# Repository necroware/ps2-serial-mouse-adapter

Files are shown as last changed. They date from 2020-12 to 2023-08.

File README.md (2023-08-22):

# PS/2 to Serial Mouse Adapter

Many retro PCs were used with serial port mouse and don't have any PS/2 ports.
Unfortunately most of the serial mice are broken or expensive today. Furthermore
they were mechanical devices with a heavy steel ball to track the movement. This
mechanics got dirty quite fast and was not the best user experience anyway. A
better solution are optical PS/2 mice, most of which unfortunately would not 
work on a serial port. This adapter can be used to connect such a PS/2 mouse to
a serial port of a retro PC.The Adapter is made from through-hole parts only, so
it is very easy to solder and due to Arduino based solution, it is also a very
nice device for tinkering, experimenting and learning about mouse protocols.

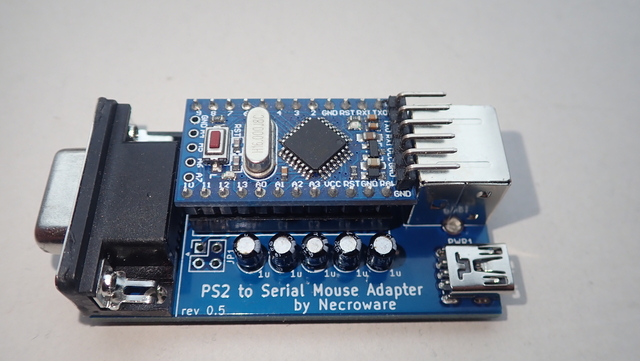
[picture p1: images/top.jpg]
ps2-adapter


## How does it work?

The serial port on the computer communicates with the mouse using basically two
pins - RTS and RX. RTS is used for notification and RX for the actual data
transfer, which contains mouse position, buttons state etcetera. A standard PS/2
mouse on the other hand uses completely incompatible protocol and transfers the
data between the mouse and the computer using the Data and Clock pins. If we
want to connect a PS/2 mouse, to a serial port, we need some instance in
between, to translate between the two different protocols. In this adapter the
translation is done using an Arduino Mini. However, there is another problem.
PS/2 mouse  protocol uses so called TTL logic, which simply means, that the
voltage of 0V means a logical zero and 5V means a logical one. TTL logic is what
Arduino uses as well, but a serial port, or also called RS232, uses another
voltage levels. Any voltage below -3V is a logical one and a voltage above +3V
is a logical zero. So, it is not possible to connect Arduino output directly to
the serial port. It simply will not work and needs another translator, which
converts TTL voltage level to RS232 levels. In this adapter such conversion is
made by a well known MAX232 IC. The software is written in C/C++, it is a simple
Arduino project, which can be used in Arduino Studio as usual.

## How to use?

This project contains everything you need to build your own adapter. You can
use the gerber files to order a PCB. The list of materials is below. After
soldering the adapter, connect the Arduino Mini using an USB to TTL adapter to
your PC and flash the firmware using the Arduino IDE. If you don't know how to
do that, please refer to the documentation of Arduino. 

**ATTENTION!** *The USB port (PWR1) on the adapter is only for powering the
circuits, it is not a data port!*

Connecting the adapter to the PC is very simple. Plug your PS/2 Mouse into the
adapter, connect a mini USB cable to power the adapter. Plug the adapter into a
serial port of your PC. Turn on the PC and use a serial mouse driver of your
choice. The adapter was tested with Microsoft, Logitech and Cute mouse drivers.
Cute Mouse Driver is part of FreeDos project and is free and open source.

## Jumper Settings

There are two jumpers, which can be used to set different modes. Currently you
can choose between 2- and 3-button mouse modes and select so called remote and
streaming mode. Remote mode sends mouse data all the time and has a better
response times in current implementation. Streaming mode sends only data, when
mouse position or button state changes. Unfortunately, this mode is currently
not in a good shape. It has a higher delay and can result in some timing
issues. However, it is interesting to have it for experimental purpose. Default
values are when the jumpers are unset.

JP1 | Setting |Description
----|---------|------------------------------
1-2 | unset   | 3-button Logitech mouse
1-2 | set     | 2-button Microsoft mouse
3-4 | unset   | remote mode
3-4 | set     | streaming mode (experimental)

## Bill of materials

Reference  |#  |LCSC   |Description
-----------|---|-------|------------------------------------------
U1         |1  |       | Arduino Pro Mini 5V (ATMega168 or better)
U2         |1  |C911187| MAX232 or compatible DIP16 package
RS232      |1  |C141882| DB9 female RS232 port
MOUSE1     |1  |C77848 | PS/2 female port
PWR1       |1  |C46398 | Mini-USB port for power supply
C1-5       |5  |C106448| 1µF electrolytic capacitor
R1         |1  |C57436 | 10kOhm resistor (pull-up)
JP1        |1  |       | 2x2 jumper header (optional)

## Known issues

The code is still in development. It works, but it still has some flaws. Timing
is really important in this project and sometimes mouse drivers seem not to get
a response in time from the adapter. Usually just executing the driver once
again will initialize the mouse.

## Tested Mice

If you test the adapter with a mouse, which is not in this list please consider
to submit a report to improve the compatibility of the adapter.

* Logitech Optical Mouse M-BT58 (USB, PS/2, Optical)
* NagerIT Fair Mouse (USB, PS/2, Optical)
* Typthoon Optical Mouse (USB, PS/2, Optical)
* Microsoft IntelliMouse Optical (USB, PS/2, Optical)
* Microsoft IntelliMouse "Classic" (PS/2, Balled)
* Microsoft Basic Optical Mouse (USB, PS/2, Optical, produced 2021)
* Microsoft Comfort Optical Mouse 300 (USB, PS/2, Optical)
* IBM 33G5430 (PS/2, Mechanical)

## Links

* [PS/2 Mouse Protocol description](https://isdaman.com/alsos/hardware/mouse/ps2interface.htm)
* [More PS/2 Mouse Protocol description](http://www-ug.eecg.utoronto.ca/desl/nios_devices_SoC/datasheets/PS2%20Protocol.htm)
* [Serial Mouse Protocol description](https://linux.die.net/man/4/mouse)
* [Cute Mouse Driver](http://cutemouse.sourceforge.net)

## Special Thanks
* creopard from dosreloaded.de for testing with MS IntelliMouse Optical
* moravec from dosreloaded.de for donating the original IBM 33G5430 mechanical mouse

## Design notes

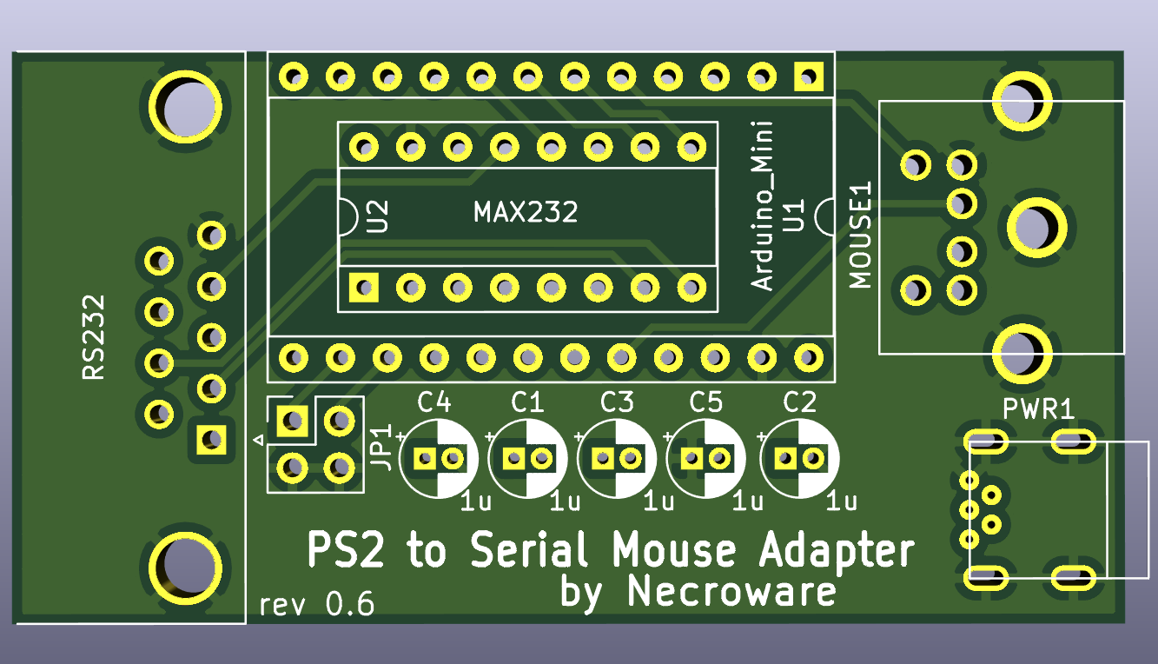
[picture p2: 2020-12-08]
images/ps2-serial-mouse-adapter-pcb.png

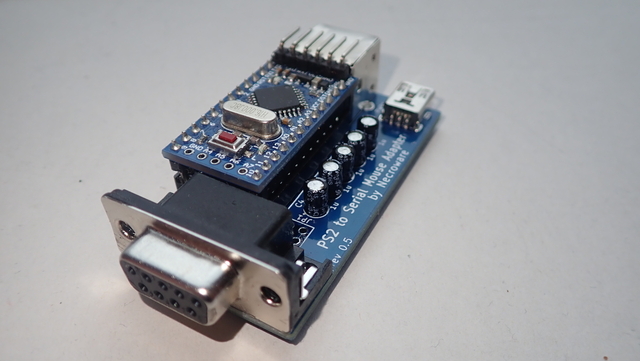
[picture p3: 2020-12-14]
images/front.jpg

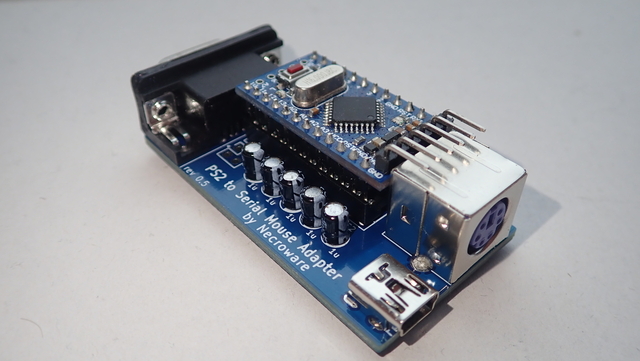
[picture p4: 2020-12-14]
images/back.jpg

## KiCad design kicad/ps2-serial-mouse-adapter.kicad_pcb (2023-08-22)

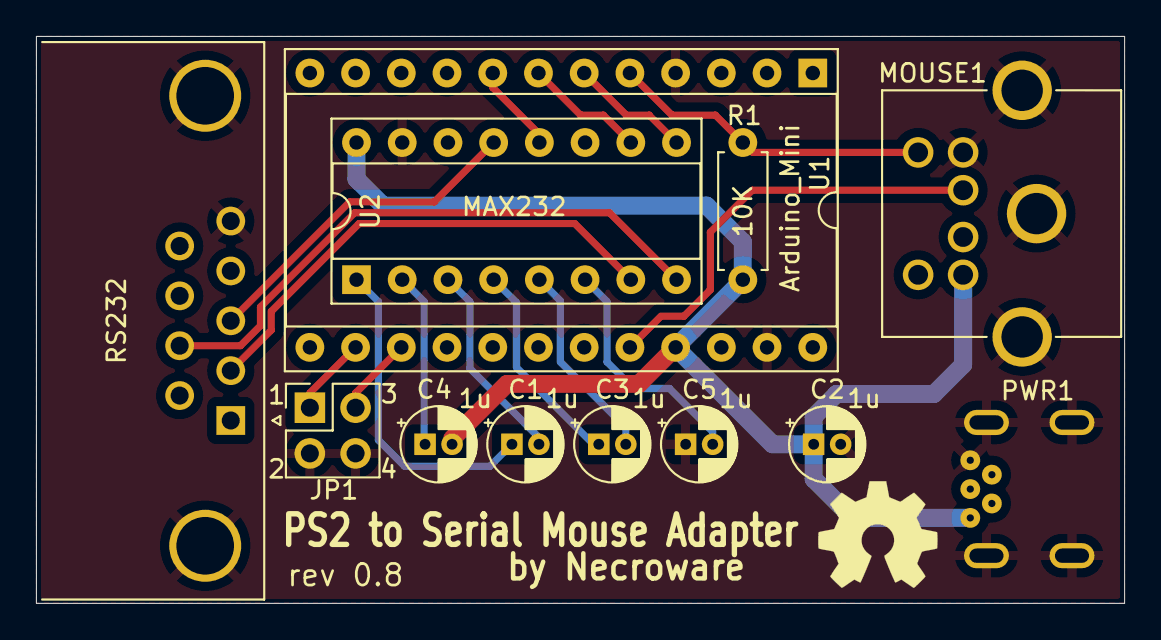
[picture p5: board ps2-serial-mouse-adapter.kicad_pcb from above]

Board: 2 copper layers, 60.5 x 31.5 mm, 12 parts (0 on the bottom side), 18 nets.

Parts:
C1, C2, C3, C4, C5: 1u; CP_Radial_D4.0mm_P1.50mm
JP1: Conn_02x02_Odd_Even; PinSocket_2x02_P2.54mm_Vertical
MOUSE1: Mini-DIN-6; Mini_DIN_6_LCSC_C77848
PWR1: USB_B_Mini; USB_Mini-B-Jing_Extension_LSCS_C46398
R1: 10K; R_Axial_DIN0207_L6.3mm_D2.5mm_P7.62mm_Horizontal
RS232: DB9_Female; DSUB-9_Female_Horizontal_P2.77x2.84mm_EdgePinOffset7.70mm_H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
U1: Arduino_Mini; DIP-24_W15.24mm_Socket
U2: MAX232; DIP-16_W7.62mm_Socket

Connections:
CLK: MOUSE1.5, R1.2, U1.5 (D2)
DATA: MOUSE1.1, U1.20 (A3)
GND: C2.2, C5.1, JP1.2, JP1.4, MOUSE1.3, MOUSE1.7, PWR1.5 (GND), PWR1.6 (Shield), RS232.0 (PAD), RS232.5, U1.4 (GND), U1.23 (GND), U2.15 (GND)
unnamed: JP1.1, U1.14 (D11)
unnamed: JP1.3, U1.15 (D12)
unnamed: C2.1, C4.2, MOUSE1.4, PWR1.1 (VBUS), R1.1, U1.21 (VCC), U2.16 (VCC)
unnamed: C1.1, U2.1 (C1+)
unnamed: C1.2, U2.3 (C1-)
unnamed: C3.1, U2.4 (C2+)
unnamed: C3.2, U2.5 (C2-)
unnamed: RS232.3, U2.13 (R1IN)
unnamed: RS232.7, U2.8 (R2IN)
unnamed: RS232.2, U2.7 (T2OUT)
unnamed: C4.1, U2.2 (VS+)
unnamed: C5.2, U2.6 (VS-)
RTS: U1.6 (D3), U2.9 (R2OUT)
RX: U1.8 (D5), U2.12 (R1OUT)
TX: U1.7 (D4), U2.10 (T2IN)

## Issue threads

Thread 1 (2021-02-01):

Use software serial instead

cocus, 2021-02-01:
Hi! I found your project thru your Youtube channel. I figured that you want to improve it further, and I think you can use the SoftwareSerial provided by the Arduino framework so you don't have to use a hardcoded way to send bytes; and you should also gain being "agnostic" of the CPU clock, since that should be handled by that class.
I could try to make the changes, but I don't have the appropriate hardware to even test this.

necroware, 2021-02-01:
Hi! My first implementation was around SoftwareSerial, but for some reason, it didn't work back then. I don't quite remember why, because it was more, then 3 years ago. I think it was something with format, SoftwareSerial sent  using 8N1, but the old controllers need 8N2. You can configure it in normal Serial, but not in SoftwareSerial.... May be I have to give it another try, because I'm not 100% sure if it was it...

cocus, 2021-02-01:
Oh I see. I checked again, and seems there's no support for the 8N2 on the software serial :( there are other libraries that should support it, but since you already have implemented and adding a third party lib is usually a pain, I think this soulution should suffice. Probably a small change on the baud rate calculation should be added so the F_CPU is considered; but that's entirely optional.
Thanks!

necroware, 2021-02-01:
Thank you very much for your suggestion. My code at that point is really very simple, may be too simple :D I already refactored it on a local branch, and moved serial code from the main file, but I still have to merge it into the master. I will consider to use F_CPU for the baud rate calculation. If you have an example, how you'd like to see it, just post a comment here and I'll test it and integrate it into the code, if it works.

cocus, 2021-02-01:
So, having a look at the original SoftwareSerial.cpp from Arduino, I can see that they calculate the bit delay with this code:
```
  // Precalculate the various delays, in number of 4-cycle delays
  uint16_t bit_delay = (F_CPU / speed) / 4;

  // 12 (gcc 4.8.2) or 13 (gcc 4.3.2) cycles from start bit to first bit,
  // 15 (gcc 4.8.2) or 16 (gcc 4.3.2) cycles between bits,
  // 12 (gcc 4.8.2) or 14 (gcc 4.3.2) cycles from last bit to stop bit
  // These are all close enough to just use 15 cycles, since the inter-bit
  // timings are the most critical (deviations stack 8 times)
  _tx_delay = subtract_cap(bit_delay, 15 / 4);
```
`subtract_cap` is defined at https://github.com/arduino/ArduinoCore-avr/blob/9f8d27f09f3bbd1da1374b5549a82bda55d45d44/libraries/SoftwareSerial/src/SoftwareSerial.cpp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

Then, in the bit send loop, they call `_delay_loop_2` which I can only assume it is defined on `#include <util/delay_basic.h>`.

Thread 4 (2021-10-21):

Mouse stuck in PS/2 communication

necroware, 2021-10-21:
Some mice seem to stuck in the PS/2 communication. So far two mice had such a problem - HP and A4tech. The behavior is the same on both, lights up but gets stuck at (serial monitor output):

Starting serial port
Init 3-buttons mode
Listening on RTS
Reseting PS/2 mouse

Closed 2022-01-12.

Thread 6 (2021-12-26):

Can't support Windows 98?

denjhang, 2021-12-26:
I connected the adapter to the serial port of my 586 motherboard according to the correct method, and then turned it on again. I found that although Windows 98 can recognize the mouse normally, when I move the mouse, there is no response at all, and there is no response when I click the left and right buttons of the mouse. Only when I press the reset button of the arduino, there is a small probability that the mouse will move for a moment.

denjhang, 2021-12-26:
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

denjhang, 2021-12-26:
Of course, this mouse is a bargain without a brand, but I don't think this is a problem. Because the mouse can be used normally on MSX with another converter.

necroware, 2021-12-26:
Which software version did you use? If you used the one from the release, would you please try the HEAD from main? There is a fix for streaming mode bug (see #2)

Furthermore some mice seem to have problems with the unstable clock. You can try to add a 10k or less resistor between the clock pin (5) and the VCC pin (21) of the Arduino. See the picture in #4. If this is the problem with your mouse, the fixed PCB design is already waiting for the merge.

creopard, 2021-12-26:
In general, the adapter works flawlessly with Windows 98 (as an example Windows 98 SE and a Microsoft IntelliMouse Optical):

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

You could also try to check your IRQ settings.
Is your "autoexec.bat" free from any "ctmouse.exe" entries?

denjhang, 2021-12-26:
I found out that my "autoexec.bat" is empty and there is nothing in it.

necroware, 2021-12-26:
That's good. Then try the things I wrote previously. The latest software from the main brunch and/or the pull-up resistor on the clock pin.

denjhang, 2021-12-26:
I tried to connect a 10K resistor, and found that after the mouse started in Windows 98, it quickly moved to the lower left corner of the screen and kept pressing the right button of the mouse.

necroware, 2021-12-26:
Ok, that's a progress. As I said, some mice seem to have problems with the clock stability. If you have other resistor values at hand it would be nice if you can try them. something between 20kOhm and 4,7kOhm. I would really like to know, which one works better. So far we found only one mouse which had some issues and we could solve them by using a 10kOhm resistor.

I think this issue here is a duplicate of #4 so far. Can you please also try to change the code in one place and see if something changes? You have to change the line 89 in the file Ps2Mouse.cpp:

from: pinMode(m_ref.m_clockPin, INPUT_PULLUP);
into: pinMode(m_ref.m_clockPin, INPUT);

denjhang, 2021-12-26:
So far I have tried 10K and 20K, and there is no difference. As for modifying the code, I don't have a USB-TTL cable at the moment, so I should be able to test it in a few days. (Actually, this converter was made for me by other people, I am going to make one myself)

necroware, 2021-12-26:
Ok, thank you for testing. Since you can't test the latest software version, could you please set the JP1 3-4 jumper? That would enforce streaming mode and if your mouse is working with that, then it is affected by the bug #3.

Seems like the adapter has a problem with your mouse, but with your help I think we will be able to find out what's wrong. I hope, the USB-TTL shouldn't be a problem to find?

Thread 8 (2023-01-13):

Maxim MAX232 hot without topside charge pump cap

hazelutf8, 2023-01-13:
After assembling board rev v0.6, a MAXIM branded MAX232CPE got hot very quickly after first power on.

Searching online, it seems some MAX232 chips allow low or high side charge pump cap use, but the MAXIM chips require the cap be attached to VCC, and for brand compatibility it is suggested to use a high-side charge pump cap.
[How to solve MAX232 heating](https://electrosome.com/solving-max232-max3232-heating-or-burning-problem/)

In order to verify, the C4 ground-side traces were cut, two on both the top and bottom of the board, and a wire was jumped between that cap leg and +5V.
This modification was verified as working with a Microsoft "Mouse Port Compatible Mouse 2.1A" (FCC ID C3KKMP1).

Please let me know if you would like any other FW or HW tests.

necroware, 2023-01-22:
Thank you very much for this input, very interesting. I'll try this with different ICs and if everything is alright, I'll change the circuit. In the proposal, it looks like it is ok to use a polarized cap as well. What do you think about it? Would be nice to keep the capacitor types the same if possible.

hazelutf8, 2023-01-22:
I used unpolarized caps since I had them on hand.

From my reading, polarized caps are fine, and should be aligned to whichever power rail direction used.
(Your v0.6 design has cap negative leg to ground and positive to the chip, but I used positive to the positive power rail and negative to the chip pin.)

The [Maxim MAX232 datasheet rev M](https://www.ti.com/product/MAX232#tech-docs), figure 6, note B, states both polarized and unpolarized are fine.

hazelutf8, 2023-01-22:
The Maxim MAX232 datasheet also allows polarized caps of the same value, but the application circuit uses the opposite power rail for its charge cap.
https://www.analog.com/en/products/max232.html

jsantcl, 2023-04-27:
Hello, I built one using the same max232cpe, got really hot and the mouse is not detected by computer, it's turning the infrared on but no luck with the ctmouse scan. Any troubleshooting instrucctions ? ( I'm no electronic expert just followed the instrucction on your repo) Thanks!

necroware, 2023-04-27:
As was mentioned in  the first comment in this issue, some max232 are different and seem to be not compatible with the released circuit. max232cpe is such an example, but you can workaround that by removing C4 and soldering it between pin 2 (cap positive lead) and 16 (cap negative lead) of the max232cpe.

stevenhoneyman, 2023-08-22:
Hello! Did this hardware fix get tested since? I was going to order some PCBs to build myself one of these but if this enhancement will make it to a v0.8 release of the gerbers then I should probably wait for the fixed version. Thanks

jsantcl, 2023-08-23:
Hello, did the change for the max232 got very hot and didn't work, then tried with the TI 232 and didn't work either, maybe I've got faulty chips. Is there a way to test the 232 chip ?

jsantcl, 2024-05-03:
v0.8 fixed overheating issue, tested with
Maxim max232cpe
Ti max232n

thanks!

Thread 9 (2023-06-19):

KVM Compatibility and Fix - Streaming Mode

morphinejh, 2023-06-19:
**This is for information and, possibly, integration.**

I have a TRENDnet TK-423K that I have tried with a few types of PS/2 to serial connections. I couldn't get any of them to work consistently.

However, since you were kind enough to share this project publicly, I was able to adapt your code to get it all working! Turns out the KVM will not work in any mode except Streaming mode. In order to get it to work with the KVM switch that I have, I had to speed up the code execution - it seemed to get out of sync on the PS/2 side or stream too much information on the RS-232 side...

My solution was to use direct Port writes where ever possible as well as instantiate the mouse class directly in streaming mode from the start. Rather than initiating it and then resetting to put it in streaming mode. One issue with the code as it is now, is that `bool m_stream` is only set when initialized - therefore it is never fully in streaming mode after a `mouse.reset()` call. The check for:
`If (m_stream)` within `Ps2Mouse.cpp`
was always false since the constructor showed:
`Ps2Mouse::Ps2Mouse(byte clockPin, byte dataPin)
  : m_clockPin(clockPin), m_dataPin(dataPin), m_stream(false)
{}`

This essentially made it always send a command request for data, which came back all zeroes when the mouse was set to be in streaming mode. I don't know if this behavior is universal though, as I have only been able to test on the KVM switch.

The way I have written the adapted code makes it only compatible with an Arduino ProMicro due to the direct Port writes. However it could be adapted to another model easily. There are also new DEBUG statements that can be turned on/off. I did trying adapting just the new streaming mode constructor, but it didn't work correctly either. I believe due to the delays in Arduino's `digitalWrite()` and `digitalRead()`.

Check it out the fork and let me know your thoughts:
[https://github.com/morphinejh/ps2-serial-mouse-adapter](https://github.com/morphinejh/ps2-serial-mouse-adapter)

sweetlilmre, 2024-05-31:
@morphinejh I had a look at your fork. Direct port access is definitely the way to go here, so great addition. Why don't you raise a pull request against this repo, it would be nice to get your changes into the official source.

I have some comments on your changes, if you are interested I can fork your repo and make a pull request against it?

morphinejh, 2024-05-31:
Not a problem. I'll check it out once you do.

T0tallyN0tAR0b0t, 2025-01-06:
Hi folks,

Awesome work on the fork @morphinejh, but I was running into issues with a KVM as well, a D-Link DKVM-8E, it sometimes has a bit of a brain fart and send the cursor flying across the screen and clicking randomly. This is likely a timing issue or something, but I just didn't have time to look into it, so I took the error checking route.
When this happens, most of the time, there are parity errors on the packets or the overflow bits on the X and/or Y movement are set, so I finished implementing the parity check stub in the code and added an X/Y overflow check.
This made the adapter usable for me, but I would still occasionally have the cursor teleport across the screen, so I added a simple mechanism to trim out the movements that are above a configurable limit, this feature is enabled by a jumper(D13) and the limit value is set with a pot (A1) that can be adjusted  on-the-fly. I found in my tests that a movement >128 is very likely an error, so this solved all the issues for me.
I forked your fork and made a pull request with my code, hope it helps.

perchrh, 2025-01-06:
Nice! The additional trimpot and jumper, are they an addition to the PCB? If so, could you share updated kicad files as well? :)

T0tallyN0tAR0b0t, 2025-01-06:
> Nice! The additional trimpot and jumper, are they an addition to the PCB? If so, could you share updated kicad files as well? :)

No, sorry, kicad is still a bit intimidating to me, that is why I made the feature entirely optional, so that it didn't invalidate the current board design, that bit of code for the movement trimming can be ignored and is just there in case someone **really** needs it.
I promised myself I would I would learn kicad, it's on the list....

T0tallyN0tAR0b0t, 2025-02-09:
Hi @morphinejh,

I was still running into a lot of issues with my KVM, I implemented a bunch of error handling to address most of the issues, so that I would just get a small hiccup in the mouse movement when my KVM has a brain fart.
I tuned as much as I could all the timings, but I just couldn't get everything fixed. The challenge for me was keeping both the serial and PS/2 baud rates locked in, so in the end I resorted to implementing the serial communication over the HW Serial on the TX pin on my arduino nano.
**That worked perfectly, since the Serial message queue was now handled in HW, I could focus only on the PS/2 baud rate.**
 It works absolutely flawlessly now but you do kind of have to give up on the Serial for debugging messages (Check how I handled DEBUG...).
To test my version you should just have to bridge pin 7 (D4) to the TX pin, if it all goes well you will see the TX LED blinking with your mouse movements!
Somehow I totally missed @sweetlilmre 's PR, I am definitely going to merge  in my code! Love the wheel mouse support! But for now I am just going to enjoy some Simcity 2000.

Cheers!

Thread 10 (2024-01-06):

Tips for debugging

mudmin, 2024-01-06:

mudmin, 2024-01-06:
Are there any tips for debugging this? I've spent a fair amount of time on it and I'm not getting anywhere.  As someone said on pcbway, the 232 chip gets pretty toasty.

Cutemouse recognizes the device itself, however none of the tests work on checkit.

When I plug my Logitech mouse in, the blue light comes on on the arduino, but not on the other mice.

necroware, 2024-01-07:
You can just connect to serial monitor in your android studio and analyze the output. There are also more in depth tutorials how to to debug through the serial port. However, there is no point for debugging if your 232 chip gets hot. It would be like measuring a pulse on a corpse :)

Your issue could be a duplicate of #8. Which revision of the PCB do you use? Which 232 IC? Unfortunately there are also a lot of fakes out there. I had a delivery where 10 chips looked the same, but only 3 of them really worked in a circuit.

mudmin, 2024-01-07:
Thanks so much for the response. I love your channel.  I thought when I made the first one, I had tried to hook it to the serial monitor.  I'd have to try that again.

Regarding the board and chip...
Maxim Max232CPE +2317
Board Rev .8

Are there any issues with those?

necroware, 2024-01-07:
Hm, there was an issue with hot chips as mentioned in #8, but the Rev. 0.8 should have fixed that. Are you sure to use exact the required capacitor values? I'd also double check the polarity of the caps. The 232 chip has to remain barely warm if at all and if it gets hot there is an issue with the charge pump or with the chip itself.

mudmin, 2024-01-07:
I used 1uf caps.  I at least socketed this 232, so I have room to experiment.  I will pull it apart, check and report back. Thanks so much for your help.

Side note...
I'm AnotherMaker on youtube.  Your XT-IDE stuff has been super helpful to me. I talked about your series in this... You may also find this board helpful when you don't want to use a network card. https://youtu.be/WTBoUmHI0pU

sweetlilmre, 2024-06-17:
@mudmin I built a couple of those Mini ISA Boards, they are fantastic. The original thread and maker can be found here: https://www.vogons.org/viewtopic.php?f=46&t=82499

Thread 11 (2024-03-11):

Volt specification at 1µF electrolytic capacitor

Vanles, 2024-03-11:
Great project, thank you for that.

Which volt information do I have to consider for the 1µF electrolytic capacitor, I didn't find anything about that in the description?

Thanks
Marco

wurstsemmel85, 2024-05-21:
Hi, i used 10µf 50v. Works fine.

perchrh, 2024-05-21:
I suggest 10v as a safe minimum, as the chip is powered by 5v. You can in general use higher voltage numbers for capacitors than the requirements without negative consequences. For example 50v instead of 10v is fine.

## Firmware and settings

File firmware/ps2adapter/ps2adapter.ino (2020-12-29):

#include "Ps2Mouse.h"

static const int PS2_CLOCK = 2;
static const int PS2_DATA  = 17;
static const int RS232_RTS = 3;
static const int RS232_TX  = 4;
static const int JP12 = 11;
static const int JP34 = 12;
static const int LED = 13;

static Ps2Mouse mouse(PS2_CLOCK, PS2_DATA);
static bool threeButtons = false;

static void sendSerialBit(int data) {
  // Delay between the signals to match 1200 baud
  static const auto usDelay = 1000000 / 1200;
  digitalWrite(RS232_TX, data);
  delayMicroseconds(usDelay);
}

static void sendSerialByte(byte data) {

  // Start bit
  sendSerialBit(0);

  // Data bits
  for (int i = 0; i < 7; i++) {
    sendSerialBit((data >> i) & 0x01);
  }

  // Stop bit
  sendSerialBit(1);

  // 7+1 bits is normal mouse protocol, but some serial controllers
  // expect 8+1 bits format. We send additional stop bit to stay
  // compatible to that kind of controllers.
  sendSerialBit(1);
}

static void sendToSerial(const Ps2Mouse::Data& data) {
  auto dx = constrain(data.xMovement, -127, 127);
  auto dy = constrain(-data.yMovement, -127, 127);
  byte lb = data.leftButton ? 0x20 : 0;
  byte rb = data.rightButton ? 0x10 : 0;
  sendSerialByte(0x40 | lb | rb | ((dy >> 4) & 0xC) | ((dx >> 6) & 0x3));
  sendSerialByte(dx & 0x3F);
  sendSerialByte(dy & 0x3F);
  if (threeButtons) {
    byte mb = data.middleButton ? 0x20 : 0;
    sendSerialByte(mb);
  }
}

static void initSerialPort() {
  Serial.println("Starting serial port");
  digitalWrite(RS232_TX, HIGH);
  delayMicroseconds(10000);
  sendSerialByte('M');
  if(threeButtons) {
    sendSerialByte('3');
    Serial.println("Init 3-buttons mode");
  }
  delayMicroseconds(10000);

  Serial.println("Listening on RTS");
  void (*resetHack)() = 0;
  attachInterrupt(digitalPinToInterrupt(RS232_RTS), resetHack, FALLING);
}

static void initPs2Port() {
  Serial.println("Reseting PS/2 mouse");
  mouse.reset();
  mouse.setSampleRate(20);

  Ps2Mouse::Settings settings;
  if (mouse.getSettings(settings)) {
    Serial.print("scaling = ");
    Serial.println(settings.scaling);
    Serial.print("resolution = ");
    Serial.println(settings.resolution);
    Serial.print("samplingRate = ");
    Serial.println(settings.sampleRate);
  }
}

void setup() {
  // PS/2 Data input must be initialized shortly after power on,
  // or the mouse will not initialize
  pinMode(PS2_DATA, INPUT_PULLUP);
  pinMode(RS232_TX, OUTPUT);
  pinMode(JP12, INPUT_PULLUP);
  pinMode(JP34, INPUT_PULLUP);
  pinMode(LED, OUTPUT);
  digitalWrite(LED, HIGH);
  threeButtons = digitalRead(JP12);
  Serial.begin(115200);
  initSerialPort();
  initPs2Port();
  Serial.println("Setup done!");
  digitalWrite(LED, LOW);
  if (digitalRead(JP34) == LOW) {
    Serial.println("Enabling streaming mode");
    mouse.enableStreaming();
  }
}

void loop() {
  Ps2Mouse::Data data;
  if (mouse.readData(data)) {
    sendToSerial(data);
  }
}

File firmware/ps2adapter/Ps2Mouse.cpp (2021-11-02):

#include "Ps2Mouse.h"

namespace {

struct Status {

  byte rightButton   : 1;
  byte middleButton  : 1;
  byte leftButton    : 1;
  byte na2           : 1;
  byte scaling       : 1;
  byte dataReporting : 1;
  byte remoteMode    : 1;
  byte na1           : 1;

  byte resolution;
  byte sampleRate;
};

struct Packet {

  byte leftButton    : 1;
  byte rightButton   : 1;
  byte middleButton  : 1;
  byte na            : 1;
  byte xSign         : 1;
  byte ySign         : 1;
  byte xOverflow     : 1;
  byte yOverflow     : 1;

  byte xMovement;
  byte yMovement;
};

enum class Command {
  disableScaling        = 0xE6,
  enableScaling         = 0xE7,
  setResolution         = 0xE8,
  statusRequest         = 0xE9,
  setStreamMode         = 0xEA,
  readData              = 0xEB,
  resetWrapMode         = 0xEC, // Not implemented
  setWrapMode           = 0xEE, // Not implemented
  reset                 = 0xFF,
  setRemoteMode         = 0xF0,
  getDeviceId           = 0xF2, // Not implemented
  setSampleRate         = 0xF3,
  enableDataReporting   = 0xF4,
  disableDataReporting  = 0xF5,
  setDefaults           = 0xF6, // Not implemented
};

enum class Response {
  isMouse        = 0x00,
  selfTestPassed = 0xAA,
  ack            = 0xFA,
  error          = 0xFC,
  resend         = 0xFE,
};

} // namespace

struct Ps2Mouse::Impl {
  const Ps2Mouse& m_ref;

  void sendBit(int value) const {
    while (digitalRead(m_ref.m_clockPin) != LOW) {}
    digitalWrite(m_ref.m_dataPin, value);
    while (digitalRead(m_ref.m_clockPin) != HIGH) {}
  }

  int recvBit() const {
    while (digitalRead(m_ref.m_clockPin) != LOW) {}
    auto result = digitalRead(m_ref.m_dataPin);
    while (digitalRead(m_ref.m_clockPin) != HIGH) {}
    return result;
  }

  bool sendByte(byte value) const {

    // Inhibit communication
    pinMode(m_ref.m_clockPin, OUTPUT);
    digitalWrite(m_ref.m_clockPin, LOW);
    delayMicroseconds(10);

    // Set start bit and release the clock
    pinMode(m_ref.m_dataPin, OUTPUT);
    digitalWrite(m_ref.m_dataPin, LOW);
    pinMode(m_ref.m_clockPin, INPUT_PULLUP);

    // Send data bits
    byte parity = 1;
    for (auto i = 0; i < 8; i++) {
      byte nextBit = (value >> i) & 0x01;
      parity ^= nextBit;
      sendBit(nextBit);
    }

    // Send parity bit
    sendBit(parity);

    // Send stop bit
    sendBit(1);

    // Enter receive mode and wait for ACK bit
    pinMode(m_ref.m_dataPin, INPUT);
    return recvBit() == 0;
  }

  bool recvByte(byte& value) const {

    // Enter receive mode
    pinMode(m_ref.m_clockPin, INPUT);
    pinMode(m_ref.m_dataPin, INPUT);

    // Receive start bit
    if (recvBit() != 0) {
      return false;
    }

    // Receive data bits
    value = 0;
    byte parity = 1;
    for (int i = 0; i < 8; i++) {
      byte nextBit = recvBit();
      value |= nextBit << i;
      parity ^= nextBit;
    }

    // Receive and check parity bit
    recvBit(); // TODO check parity

    // Receive stop bit
    recvBit();

    return true;
  }

  template <typename T>
  bool sendData(const T& data) const {
    auto ptr = reinterpret_cast<const byte*>(&data);
    for (auto i = 0; i < sizeof(data); i++) {
      if (!sendByte(ptr[i])) {
        return false;
      }
    }
    return true;
  }

  template <typename T>
  bool recvData(T& data) const {
    auto ptr = reinterpret_cast<byte*>(&data);
    for (auto i = 0u; i < sizeof(data); i++) {
      if (!recvByte(ptr[i])) {
        return false;
      }
    }
    return true;
  }

  bool sendByteWithAck(byte value) const {
    while (true) {
      if (sendByte(value)) {
        byte response;
        if (recvByte(response)) {
          if (response == static_cast<byte>(Response::resend)) {
            continue;
          }
          return response == static_cast<byte>(Response::ack);
        }
      }
      return false;
    }
  }

  bool sendCommand(Command command) const {
    return sendByteWithAck(static_cast<byte>(command));
  }

  bool sendCommand(Command command, byte setting) const {
    return sendCommand(command) && sendByteWithAck(setting);
  }

  bool getStatus(Status& status) const {
    return sendCommand(Command::statusRequest) && recvData(status);
  }
};

Ps2Mouse::Ps2Mouse(int clockPin, int dataPin)
  : m_clockPin(clockPin), m_dataPin(dataPin), m_stream(false)
{}

bool Ps2Mouse::reset() const {
  Impl impl{*this};
  if (!impl.sendCommand(Command::reset)) {
      return false;
  }

  byte reply;
  if (!impl.recvByte(reply) || reply != byte(Response::selfTestPassed)) {
      return false;
  }

  if (!impl.recvByte(reply) || reply != byte(Response::isMouse)) {
      return false;
  }

  return disableStreaming() && impl.sendCommand(Command::enableDataReporting);
}

bool Ps2Mouse::enableStreaming() const {
  return Impl{*this}.sendCommand(Command::setStreamMode);
}

bool Ps2Mouse::disableStreaming() const {
  return Impl{*this}.sendCommand(Command::setRemoteMode);
}

bool Ps2Mouse::setScaling(bool flag) const {
  return Impl{*this}.sendCommand(flag ? Command::enableScaling : Command::disableScaling);
}

bool Ps2Mouse::setResolution(byte resolution) const {
  return Impl{*this}.sendCommand(Command::setResolution, resolution);
}

bool Ps2Mouse::setSampleRate(byte sampleRate) const {
  return Impl{*this}.sendCommand(Command::setSampleRate, sampleRate);
}

bool Ps2Mouse::getSettings(Settings& settings) const {
  Status status;
  if (Impl{*this}.getStatus(status)) {
    settings.scaling = status.scaling;
    settings.resolution = status.resolution;
    settings.sampleRate = status.sampleRate;
    return true;
  }
  return false;
}

bool Ps2Mouse::readData(Data& data) const {

  Impl impl{*this};

  if (m_stream) {
     if (digitalRead(m_clockPin) != LOW) {
       return false;
     }
  }
  else if (!impl.sendCommand(Command::readData)) {
    return false;
  }

  Packet packet;
  if (!impl.recvData(packet)) {
    return false;
  }

  data.leftButton = packet.leftButton;
  data.middleButton = packet.middleButton;
  data.rightButton = packet.rightButton;
  data.xMovement = (packet.xSign ? -0x100 : 0) | packet.xMovement;
  data.yMovement = (packet.ySign ? -0x100 : 0) | packet.yMovement;
  return true;
}

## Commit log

2020-11-21 Shrink PCB
    [ps2-serial-mouse-adapter.kicad_pcb, ps2-serial-mouse-adapter.sch]
2020-11-21 Move MAX232 under the Arduino to save space
    [ps2-serial-mouse-adapter.kicad_pcb, ps2-serial-mouse-adapter.sch]
2020-11-22 Add jumpers, fix pwr1
    [ps2-serial-mouse-adapter.kicad_pcb, ps2-serial-mouse-adapter.sch]
2020-11-22 Update PWR1
    [ps2-serial-mouse-adapter.kicad_pcb]
2020-11-23 Add gerber files
    [ps2-serial-mouse-adapter-B_Cu.gbr, ps2-serial-mouse-adapter-B_Mask.gbr, ps2-serial-mouse-adapter-B_Paste.gbr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]
2020-11-23 Move Kicad files into subfolder
    [ps2-serial-mouse-adapter.kicad_pcb, ps2-serial-mouse-adapter.sch]
2020-11-23 Move gerber files into subfolder
    [ps2-serial-mouse-adapter-B_Cu.gbr, ps2-serial-mouse-adapter-B_Mask.gbr, ps2-serial-mouse-adapter-B_Paste.gbr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]
2020-11-23 Traces cleanup
    [ps2-serial-mouse-adapter.kicad_pcb]
2020-11-23 Update gerber files, minor cleanups
    [ps2-serial-mouse-adapter-B_Cu.gbr, ps2-serial-mouse-adapter-B_Mask.gbr, ps2-serial-mouse-adapter-B_Paste.gbr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]
2020-11-23 Add necroware kicad library
    [ps2-serial-mouse-adapter.kicad_pcb, ps2-serial-mouse-adapter.sch]
2020-11-23 Regenrated gerber files
    [ps2-serial-mouse-adapter-B_Cu.gbr, ps2-serial-mouse-adapter-B_Mask.gbr, ps2-serial-mouse-adapter-B_Paste.gbr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]
2020-11-23 Update LSCS part number
    [ps2-serial-mouse-adapter.sch]
2020-12-08 Replace DB9 by DB9_mounting_holes
    [ps2-serial-mouse-adapter.kicad_pcb, ps2-serial-mouse-adapter.sch]
2020-12-08 Fix wrong VCC network
    [ps2-serial-mouse-adapter-B_Cu.gbr, ps2-serial-mouse-adapter-B_Mask.gbr, ps2-serial-mouse-adapter-B_Paste.gbr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]
2020-12-13 Move code into subfolder.
    Else arduino studio complains about the project name
2020-12-22 Reset on interrupt
2020-12-22 Use arduino pod types
2020-12-23 Move init code into setup function.
    Also improved compatibility with Logitech driver
2020-12-29 Simplified streaming mode switching
2020-12-29 Implement 2-/3-button mode switch
2020-12-29 Add streaming mode switch
2021-01-10 Add MS mouse to the list of tested devices
2021-01-13 Removed gerber files from the project
    [ps2-serial-mouse-adapter-B_Cu.gbr, ps2-serial-mouse-adapter-B_Mask.gbr, ps2-serial-mouse-adapter-B_Paste.gbr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]
2021-01-13 Replace serial DTR through TX.
    DTR was not used anyway and TX can be used in the future for
    communication with the adapter through serial port
    [ps2-serial-mouse-adapter.kicad_pcb, ps2-serial-mouse-adapter.sch]
2021-01-18 Add IBM Mouse to the list of tested devices
2021-10-22 Add a pull-up resistor to the ps/2 clock
    [ps2-serial-mouse-adapter.kicad_pcb, ps2-serial-mouse-adapter.sch]
2021-11-02 Code clean up, fixed warnings
    [Ps2Mouse.cpp]
2023-08-22 Added LCSC part number for R1
    [ps2-serial-mouse-adapter.sch]
2023-08-22 Updated project to KiCad 6.0.x
    [ps2-serial-mouse-adapter.kicad_pcb, ps2-serial-mouse-adapter.kicad_sch, ps2-serial-mouse-adapter.sch]
2023-08-22 Switched charge pump from GND to VCC
    [ps2-serial-mouse-adapter.kicad_pcb, ps2-serial-mouse-adapter.kicad_sch]
2023-08-22 Warnings fixed
    [ps2-serial-mouse-adapter.kicad_pcb]
